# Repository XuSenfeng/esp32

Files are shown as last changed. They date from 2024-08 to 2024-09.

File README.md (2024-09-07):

# esp32
通过这一个项目可以实现一个带有氛围灯的esp32 Wifi 天气时钟, 这一个项目里面的教程包括PCB设计, 3D打印外壳的设计, 软件的设计

成品图片

[这一个是v1.0的的测试视频](https://www.bilibili.com/video/BV1RnYReXEdh/?spm_id_from=333.999.0.0), 目前这一个开发板的硬件还有一点bug(led的灯光不稳定), 目前猜测是电压问题或者信号干扰, 但是由于最近比较忙一直没有实际测试, 以后有时间会优化的

目前在测试Mqtt远程实现一个弹窗信息提示

其他的学习资料可以看一下这一个[嵌入式学习路线 (know-cnu.wiki)](https://embedded-study-guide.know-cnu.wiki/)

实际使用的是ESP-IDF v5.1.4



使用自己的分区表



lvgl使用QR库

```c
dependencies:
  espressif/esp_lcd_touch:
    component_hash: d4d8f2dc33205797169a97a02e0d89a8982f59fe0509129b54422052b8522f59
    source:
      storage_url: file:///E:/alearn/ESP-IDF-5_1_4/Espressif/registry
      type: service
    version: 1.1.1
  espressif/zlib:
    component_hash: 999ec50086ac1c82b8321d8f540dc9fd10f5622948b935558aa16b4b66e95d9d
    source:
      type: service
    version: 1.3.0
  espressif__esp_lcd_touch_ft5x06:
    component_hash: null
    source:
      path: E:\JHY\esp32\ESP-IDF\2024-8-3-jiao-ESP32\components\espressif__esp_lcd_touch_ft5x06
      type: local
    version: 1.0.6
  idf:
    component_hash: null
    source:
      type: idf
    version: 5.1.4
  lvgl/lvgl:
    component_hash: 948bff879a345149b83065535bbc4a026ce9f47498a22881e432a264b9098015
    source:
      storage_url: file:///E:/alearn/ESP-IDF-5_1_4/Espressif/registry
      type: service
    version: 8.3.11
manifest_hash: f8acd3c53fe97b7bd7f866e9e690cc329aa47d9190d9542797e4897a80c30134
target: esp32
version: 1.0.0
```

> 使用的组件和版本

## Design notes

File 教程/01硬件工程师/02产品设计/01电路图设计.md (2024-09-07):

---
layout: post
title: "电路图设计" 
date:   2024-8-5 15:39:08 +0800
tags: 教程
---

# 电路图设计

## 产品需求

1. 想要一个物联网适合练手的产品, 简单, 成本低, 可以练习的方向比较多
2. 想要一个屏幕, 用于和用户进行交互
3. 实际使用的时候可以保证有一种简单的交互方式
4. 装饰性
5. 尽量把大部分引脚印出来, 方便之后的拓展

### 器件选型

使用esp32的芯片设计一个天气时钟, 同时有多个可以操控的外设, 同时不会导致设计的难度过大

低成本外设: LED灯珠, 最好可以有多种颜色



> 选择这一个LED氛围灯常使用的LED灯珠

屏幕: 使用淘宝常见的屏幕模块



> 选择这一个成本比较低但是可以实现彩色显示的屏幕

核心芯片: 需要有WIFI, 由于有显示之类的需求, 内存比较大, 设计时候外部电路尽量比较简单, 之后会使用SPI, I2C之类的外设, 可硬件实现最好, 芯片方便购买, 综合以上的内容, 主芯片选择ESP32

这里是B站up主整理的[ESP32选型](https://www.bilibili.com/read/cv15539489/)手册, 也可以使用[官方的整理工具](https://products.espressif.com/#/product-selector?language=zh&names=)



最后选择使用这一个模块, 可以满足所有的需求

我还想实现一下获取当前的室内温湿度的功能, 这里为了简化设计直接抄了[嘉立创的设计](https://lceda001.feishu.cn/wiki/L5Qhw037viVW5MkyFXPcRLhznbe)(之后会讲)



在下载电路这里使用的是嵌入式里面比较常用的ch340系列的芯片, 为了焊接方便使用Micro-USB接口, 焊接技术比较高的也可以尝试使用USB

电源由于esp32需要3.3V电压, USB供电提供的是5V电压, 所以使用一个常用的稳压芯片AMS1117-3.3

按键的选择由于开发板的大小, 所以使用的是两个引脚的小按键

## 电路设计

电路参考:

[‌‌‌‍‌‍‬‍‌‍‍‌‍第02章.【立创·实战派ESP32-C3】开源硬件 - 飞书云文档 (feishu.cn)](https://lceda001.feishu.cn/wiki/BbarwCC29iqFESkr19fcaqrenAb)

[RYMCU - 嵌入式知识学习交流平台](https://rymcu.com/products?page=1)

资料

[模组概览｜乐鑫科技 (espressif.com)](https://www.espressif.com/zh-hans/products/modules): 记录乐鑫的各种模组

[esp32-wroom-32_datasheet_cn.pdf (espressif.com)](https://www.espressif.com/sites/default/files/documentation/esp32-wroom-32_datasheet_cn.pdf): 实际使用的模组

从这一个文件里面可以获取主体电路的设计方案



> 主要有:
>
> 1. 下载选择电路--IO0
> 2. 串口电路: TXD0, RXD0
> 3. 调试电路: JTAG没有使用
> 4. 电压电路
> 5. 复位电路

### 电压电路

从[数据手册](https://atta.szlcsc.com/upload/public/pdf/source/20210915/EA806799CEEC3F52E0A4FA8303A508AC.pdf)里面可以获取这一个芯片的基本信息



AMS1117有固定和可调两个版本可用，输出电压可以是：1.2V，1.5V，1.8V，2.5V，2.85V， 3.0V，3.3V，和5.0V。片内过热切断电路提供了过载和过热保护，以防环境温度造成过高的结温。

> 
>
> 

从[这一个手册](https://item.szlcsc.com/323882.html)可以获取一个参考电路, 我们使用的是固定电压的版本



> 对这一个电路分析, 里面有两个稳压电容用于使这一个电路的电压稳定

之后从[这一篇文章](https://blog.csdn.net/qyx3868/article/details/124667109)里面获取到了一个和参考开发板比较像的电路图, 增加了另外两个小电阻, 最后加入一个保护电路的保险丝, 即可完成这一个输入电路的设计方案, 加了一个led用于显示这一个电路是不是已经连接电压



### 下载电路

#### 一键下载电路

[ESP-Prog 下载与调试板介绍 - - — ESP-IoT-Solution latest 文档 (espressif.com)](https://docs.espressif.com/projects/esp-iot-solution/zh_CN/latest/hw-reference/ESP-Prog_guide.html)

从这一个文件里面可以获取使用ESP32-IDF的时候使用的一键下载电路



这里不同引脚起到的作用可以在我的esp32软件笔记里面找到

直接抄了一下







手册里面说默认EN引脚会使用一个电阻上拉, 但是实际测试的时候这一个引脚的电压达不到需要的电压, 所以使一个电阻进行一个弱上拉, 以及田添加了一个弱上拉

#### USB转串口







这一个芯片是经常使用的USB转串口的芯片, 由于esp32的一键下载电路里面有使用到这两个引脚, 所以在实际选择的时候可以最好选择有这两个引脚的芯片, 我最后选的芯片是CH340K这一个芯片





基本所有的引脚都可以使用到

### LED灯

由于使用的是WS28112B这一个LED灯, 所以参考他的手册设计即可

[WS2812B-2020_worldsemi_WS2812B-2020中文资料_PDF手册_价格-立创商城 (szlcsc.com)](https://item.szlcsc.com/1051115.html)



> 在实际使用的时候, 出现LED灯闪烁的情况, 猜测1. 电压不够 2. 有干扰 
>
> 由于比较忙一直没有测



### 排针

我这里是把所有的引脚都留出来了, 具体的排布是根据芯片的引脚的顺序排的

### 注意事项

1. 有的GPIO不可以进行输出
2. 串口接线需要交叉布线
3. 天线下面不能铺铜
4. 改完以后需要重新铺铜以及添加泪滴
5. 可以加一个下载使用的位置

#### IO分布

esp32的I2C和SPI可以连接任意的引脚, 所以可以随意地设计, 实际设计的时候需要注意, 有的GPIO是不可以输出的, 不能输出的按键上拉好像是不太行的, 不建议做按键输入

[esp32_datasheet_cn.pdf (espressif.com)](https://www.espressif.com/sites/default/files/documentation/esp32_datasheet_cn.pdf)这一个手册里面记录有引脚的功能

还有就是注意一下实际的引脚的作用和分布的位置, 比如LED和它的控制引脚最好离得近一点

## PCB设计

PCB直接电路图转过去, 由于嘉立创的免费打样好像限制了板子的长宽, 所以无选的比较长的一边是10cm, 另一边由于需要固定外壳, 所以我在外面留了一部分

在实际布局的时候按照[教程](https://www.bilibili.com/list/watchlater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)就可以自己实现, 所以这里说几个我遇到的注意点

1. 如果使用的是Type-c使用手工焊接会比较困难

2. 尽量让芯片离USB接口等比较高的元器件远一点

3. 屏幕我的排针是按照我的屏幕设计的

4. ESP32的天线下边最好不要有铺铜

5. 铺铜的时候注意把比较尖的位置设置一个禁止区域

6. 底层丝印在不翻转板子的情况下是镜像的

7. 过大电流的位置如果要换面多打几个孔

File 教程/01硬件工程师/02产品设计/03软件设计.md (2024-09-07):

---
layout: post
title: "软件设计" 
date:   2024-8-5 15:39:08 +0800
tags: 教程
---

# 软件设计01

时间原因, 暂时是按照各个文件的内容进行讲解, 之后有空会进行项目构建讲解



这一个程序直接使用了嘉立创开发板的屏幕驱动程序, 之后去除里面的触摸屏等, 改编而来, 之后主要讲解的是app以及bsp下面的文件, data文件大部分是lvgl网站工具生成的

## 程序分析

### 主程序

```c
#include "app_main.h"
#include "freertos/FreeRTOS.h"
#include "freertos/task.h"
#include "key.h"
void app_main(){
    key_init();
    led_init();
    xTaskCreate(spi_lcd_main, "spi_lcd_main", 4096, NULL, 5, NULL);
    xTaskCreate(wifi_main, "wifi_main", 4096, NULL, 5, NULL);
    xTaskCreate(mqtt_main, "mqtt_main", 1536, NULL, 5, NULL);
}
```

> 首先初始化一下两个使用的外设, 之后创建三个主要的线程, 分布用于图形界面显示, 网络连接的处理, 以及远程连接的处理

### 屏幕显示界面

```c
/*

                天气界面3
                   ||
   二维码1  ==  时钟界面0  ==  按键界面2
                   ||
               led控制界面4
*/
```

主要是移植了lvgl的官方示例, 把里面的触摸屏相关的示例删了

spi_lcd_main=>lvgl_screen_init初始化=>lv_demo_main显示一下主界面=>led_creen_main创建一个控制屏幕显示的任务=>不停地刷新界面

#### spi_lcd_touch.c显示初始化/控制

这一个文件里面一部分的函数是esp32官方例程里面的函数, 保持原样即可使用, 大部分是example开头的, 主要实现的功能是根据按键, Wifi等的事件显示不同的界面

最开始是头文件以及初始化一些使用到的全局变量以及宏定义

+ example_notify_lvgl_flush_ready

初始化一变量, 在初始化的时候使用这一个函数, 这一个回调函数在颜色传输结束的时候调用

+ example_lvgl_flush_cb

实际用于显示的函数, 可以在这里放上实际的显示函数\

+ example_lvgl_port_update_callback

初始化参数变化的时候会调用这一个函数, 这一个函数实际的作用是lvgl显示的旋转

+ example_increase_lvgl_tick

lvgl的时钟处理函数, 需要一段时间调用一次

+ button_read

注册的按键回调函数, 这一个文件里面把中间的按键注册为lvgl的外设, 按下这一个按键相当于点击屏幕的中间

+ lvgl_screen_init

初始化屏幕的驱动以及lvgl的初始化, 会在这一个函数里面初始化一下SPI以及把屏幕相关的设置进行初始化

之后对lvgl进行初始化, 在初始化lvgl的时候把中间的按键初始化为lvgl的一个设备

+ led_screen_change

实际处理屏幕的转换的函数

+ led_creen_main

控制屏幕变化的主函数, 这一个函数之后会被注册为一个任务

主要的功能是调用按键的处理函数, 之后根据按键的返回值处理不同的界面任务, 根据返回值处理如果是界面变化调用led_screen_change, 不是的话判断当前界面是不是时间显示界面, 是的话使用lv_update_time更新时间

这一个函数在处理按键的时候是一个限时的阻塞读取

在处理这些以后判断一下当前的屏幕是不是该息屏, 是的话关闭背光

+ spi_lcd_main

主函数, lvgl_screen_init初始化=>lv_demo_main显示一下主界面=>led_creen_main创建一个控制屏幕显示的任务=>不停地刷新界面

### 网络相关

#### lv_demo.c各个页面的显示

所有的界面的显示都是在这一个文件里面实现的

```c
LV_IMG_DECLARE(background)
LV_FONT_DECLARE(ledfont)
LV_FONT_DECLARE(wether_font)
LV_FONT_DECLARE(icon)
```

> 开始的时候使用这几行进行lvgl数据的导入, 分别是背景图片, 三种字符

之后是定义一下需要使用的全局变量, 包括时间结构体以及声明使用的外部变量, 用于获取led信息以及主要使用的用于同步的事件组EventGroupHandle_t

```c
//当前的时间
time_t now;
struct tm timeinfo;
//记录led的现在的情况
//这一个数据会在led的线程里面控制了的的随机显示
extern uint8_t led_state;
extern EventGroupHandle_t my_event_group;
```

+ led_button_cb

是在操控led随机显示页面的时候中间的按钮的回调函数, 由于初始化的时候把中间的按键初始化为lvgl的按键外设, 设置按压的位置是在屏幕的中央, 所以在这一个界面可以通过实体按键控制

+ lv_update_time

时间更新函数, 这一个函数里面会获取当前的时间, 把时间显示在屏幕

+ lv_demo_main

启动界面的demo, 显示一下基础信息以及获取时间的进度

+ lv_demo_switch

切换led随机显示的界面

+ lv_demo_time

显示时间的界面, 这一个函数会把里面的table返回, 作为之后刷新时间的时候使用

+ lv_demo_wifi

这一个函数是在Wifi连接以后显示的二维码的界面

+ lv_demo_led

控制led灯颜色的界面

+ lv_demo_get_wether

等待获取天气的页面

+ lv_qweather_icon_show

显示实际天气的图标, 依据获取的天气进行不同的显示, 在lv_demo_wether函数里面调用

+ lv_demo_wether

显示天气的界面

+ lv_demo_msg_win

弹窗初始化, 如果已经初始化, 会在这里面显示

+ deal_page4 处理led控制页面

传入的参数是按下的按键, 根据不同的按键, 更新一下当前的led的选择的位置

当这一个选择的位置是在最下面的时候, 第一次选择进入颜色选择, 第二次把这一个颜色写入

实际的当前位置使用以下三个变量进行记录

```c
int led_choice = 0; // 选择的灯
char choice_now_pos = 0; // 选择的灯的位置, 低四位为行, 高四位为列
unsigned char choic_color[3] = {255, 0, 0};
```

#### wifi.c连接wifi以及服务器

主要实现wifi里面, 初始化一个服务器, 可以用于和手机进行通信, 以及时间的获取

wifi_sta_init初始化wifi的各种数据以及开启wifi=>wifi_cb回调函数, 处理wifi的各种状态

这里面有一个wifi_main线程, 在这一个线程里面实际实现的是一个网页服务器

+ get_time

从服务器获取时间, 之后把这一个时间更新一下, 这一个函数是在界面管理的函数里面调用的

+ wifi_cb

用于wifi链接的回调函数, 在启动以后会进行wifi的链接, 链接成功设置WIFI_CONNECTED_BIT标志位

+ 两个页面

这两个页面是html格式的页面, 实际的作用分别是用于控制led, 以及成功提交以后的提示界面

+ get_handler

使用get方法访问第一个页面的时候返回第一个页面

+ post_handler

处理使用post方式访问第二个页面的函数, 会在这里解析第一个页面传过来的的数据, led_message_deal这一个函数会把字符串里面的led以及颜色信息填入led信息记录数组里面

+ _http_event_handler

http的事件理函数, 这一个函数是服务器使用的, 获取不同的http请求的时候, 会触发不同的事件

这一个函数是示例里面的函数

+ gzDecompress

GZIP的解压函数, 用于处理获取到的天气信息

+ get_now_weather

获取当前的天气, 使用API获取, 这里的API使用的是嘉立创教程里面获取的API, 获取信息以后使用gzip进行解压, 然后使用cJSON进行解析, 获取的信息记录在全局变量里面

+ wifi_main服务器主函数

在这一个函数里面注册两个页面, 分别处理不同的http请求, 之后使用网页进行操控的时候会触发_http_event_handler函数

+ wifi_sta_init初始化wifi

初始化一下wifi, 设置一下回调函数

#### mqtt.c远程连接

这一个主要是实现远程的信息通信, 使用mqtt_main为一个线程处理mqtt的信息

+ deal_message

处理mqtt获取的信息, 使用cJSON进行解析, 把获取的信息进行显示, 同时使用一个led显示红色进行提醒

+ mqtt_event_fun

MQTT事件处理函数, 在连接的时候, 订阅一下Jiaoesp这一个主题, 在获取信息的时候调用deal_message处理信息

### 驱动

#### jiao_i2c.c i2c的驱动文件

由于我的开发板没有焊接温湿度传感器, 所以暂时没有使用, 这一个文件里面实际是一个初始化i2c

#### key.c 按键处理

在这一个文件实现按键的处理, 主要是各个页面的切换

+ page4_init

在进入page4之前把用于记录信息的全局变量清零一下

+ key_deal 处理实际的按键

依据当前的按键的位置, 进行不同的处理, 返回值是一个char数组, [0]: 是否需要处, [1]: 当前的页面, 这一个函数的调用是在lvgl的界面处理函数例程面, 使用xQueueReceive阻塞, 如果返回界面需要变化的时候清空一下对弹窗的记录信息

如果当前是息屏, 唤醒屏幕

+ key_isr_handler

中断处理函数, 在这里面把获取的当前的按使用Queue发送处理, 发送的数据会在key_deal函数里面进行处理

+ key_init

初始化一下按键的gpio以及注册一下按键的中断处理函数

#### led_control.c

ws2812b的驱动函数

开始的时候是一些方便操控的宏定义, 之后是一些用于实现通信协议的函数比如delay_ns, ws2812b_rst, ws2812b_writebyte_byt, ws2812b_write_rgb_byte

在这一个文件里面, 我使用led_color这一个数组记录所有的led的颜色, 有几个用于设置里面的颜色的函数, w2812b_close_color_set关灯, getrandom_color获取一个随机的颜色, init_random_led_color把所有灯设置为随机颜色

+ led_flash

把led_color里面的颜色进行实际的显示

+ led_update_color

page4里面的处理函数, 用于把当前的设置的led进行实际的设置以及显示

+ led_message_deal

处理http获取的post信息, 获取要设置的led和颜色, 最后进行刷新

+ led_close

关灯

+ ws2812_task

led的任务, 这一个任务的功能是进行led的实时显示, 用于实现随机led显示等

+ start_task

启动任务

+ gpio_pad_select_gpio

初始化一个led的引脚

+ led_init

初始化函数, 初始化gpio以及启动一下这一个任务

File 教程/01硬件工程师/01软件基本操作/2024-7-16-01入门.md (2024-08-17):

---
layout: post
title: "入门" 
date:   2024-7-14 15:39:08 +0800
tags: Linux 网络
---

# 软件下载

使用立创EDA

[软件下载 - 嘉立创EDA (lceda.cn)](https://lceda.cn/page/download?src=index)



下载激活即可

## PCB定义

Printed Circuit Board 印刷电路板

作为元器件的制成, 实现电子元器件的连接

### 层叠结构

在铜皮上面做减法, 去除不需要的部分, 铜皮容易被折断, 所以把铜皮放在一个基板上面,直接裸露的时候, 这一个铜皮容易被腐蚀,  覆盖一层绝缘的绿油(阻焊), 同时可以防止触电, 还可以防止焊锡乱走

在板子上面做一些标志, 标志的名字叫做丝印

元器件比较多的时候, 连接比较复杂, 这时候可以有多层的铜皮, 不同的层之间可以进行打孔进行连接

内部的线和外部的器件进行连接的时候, 需要根据不同的封装设计不同的接触面积, 体现在PCB就是裸露的焊盘, 使用阻焊开窗的方式实现





>   它可以在PCB工厂制造。一般情况下，四层板芯两侧压一铜箔，三层板芯一侧压一铜箔。就工艺流程而言，有必要进行冲压。
>
>   两种工艺成本的差异在于，四层板材多了一层铜箔和粘合层，成本差异不大。板材厂报价时，一般以3-4层的报价为一个等级，报价以偶数定义（当然不止多层）。例如，如果你设计了五层板，对方会按照六层板的价格报价，即你设计了三层板的价格，价格与你设计的四层板的价格相同。
>
>   在PCB工艺中，四层板比三层板更容易控制。主要在对称性方面，四层板的翘曲度可控制在0.7%以下（ipc600标准）。然而，当三层板的尺寸较大时，翘曲将超过该标准，这将影响SMT贴片和整个产品的可靠性。因此，普通设计师不设计奇数层板，即使奇数层实现了功能，也将设计为伪偶数层，即5层设计为6层，7层设计为8层。
>

### 通孔, 盲孔, 埋孔

通孔: 从顶层到底层, 这一个PCB板被打通了, 内部镀铜

盲孔: 没有打通, 连接其中几层, 但是外部可以看到, 所以起点是第一层

埋孔: 进行内层的切换, 也是没有打通的

## 元器件符号和封装

元件在PCB上面的形式



> 黄色的是丝印层, 灰色的是焊盘的范围, 红色的是实际的焊盘, 每一个引脚对应一个焊盘

## 生产

+ 开料, 圆角, 刨边

开料把原始的覆铜板割为可以制作板子的过程, 铺铜板是双层板, 其余的多层板是使用这一个板子粘合而来的

+ 钻孔

这个时候孔里面是没有铜的, 根据实际有孔的层进行打孔

+ 沉铜

PCB在沉铜缸里面通过氧化还原对孔进行金属化

+ 压膜

铜箔板的两个面各贴一张蓝色的感光膜。

感光膜作用是在铜箔板上完成线路的印制，它只在铜箔板上保留一段时间，在后续的“图电”步骤完成后，铜箔板上的膜就消失了，它的使命就完成了。

+ 曝光

线路菲林有线路的地方是黑色的，没有线路的地方是透明的，在曝光灯管的作用下，透明的地方就会充分曝光，也就是**没有线路的地方会充分曝光。**

经过曝光后，干膜上就有清晰的线路了

>  菲林就跟模具一样，而PCB就是材料。做PCB的时候，需要把没用的铜箔[蚀刻](https://zhidao.baidu.com/search?word=蚀刻&fr=iknow_pc_qb_highlight)掉。菲林就是在这里起了作用，首先，把菲林晒到网板上。

+ 显影

曝光其实就是为显影做准备。显影设备中的显影液会把没有曝光过的部分去掉，也就是说，它会把有线路的地方去掉，露出黄铜。

> 需要留下来的铜是在空气中的

+ 电铜

曝光其实就是为显影做准备。显影设备中的显影液会把没有曝光过的部分去掉，也就是说，它会把有线路的地方去掉，露出黄铜。

+ 电锡

电锡以后，有线路的地方，会再上一层锡，这里的锡，并不是我们最终拿到手电路板上的锡，这里的锡，是一种液态锡，它的作用是在下一个环节“退膜”的时候保护线路，它将会在图电工序的最后一个环节消失，完成它的使命。

+ 退膜

把蓝色的膜去掉, 只对曝光过的干膜起反应，经过两次退膜水洗，退膜就彻底完成了。

+ 蚀刻

干膜已经不见了，露出了铜，这些铜，都不是我们需要的，我们需要的铜，此时正在锡的下面。接下来板子进入蚀刻环节，目的就是把裸露的铜全部腐蚀掉。

经过蚀刻以后，刚才去掉干膜后露出的铜，就被腐蚀掉了。现在电路板上就只剩下真正需要的线路部分了。

锡没有和蚀刻药水发生反应，刚才的裸露铜部分，现在已经露出了基材。

+ 退锡

锡没有和蚀刻药水发生反应，刚才的裸露铜部分，现在已经露出了基材。

+ 光学AOI线路扫描

自动光学检测, 把待检测的电路板放到AOI仪器检测面板上，AOI仪器开始自动扫描电路板，并与MI文件中的相应文件进行对比，一旦有区别，就会停下来，把图像放大显示到显示器上。

如果是缺陷的话，看看是否能够补救，能补救的话就补救一下，不能补救的，就是生产缺陷了，然后标记一下出错地方。

AOI检测，只是针对电路板的外观进行检测，可以很好的检测出来开路、短路、断路的地方。

+ 阻焊

阻焊的目的，就是给电路板表面涂一层油，保护铜。最常见的是绿油，此外，还有蓝、黑、白、红、黄、紫等颜色。目前，嘉立创针对不同颜色的阻焊工艺，全部免费。

+ 曝光

在不需要绿油覆盖的地方，也有了绿油，比如焊盘等需要开窗的地方。为了去除这些地方的阻焊油，就需要经过曝光和显影。

曝光需要用到阻焊菲林，在菲林上，需要开窗的地方是黑色的，其它地方是透明的。经过曝光以后，透明的地方就进行了充分的曝光，黑色的地方没有被曝光，就是需要开窗的地方，没有被曝光。

+ #### 显影

也是一个化学反应的过程，显影液只对未曝光的地方起反应，所以，需要开窗的地方，就裸露出了焊盘

+ 字符

丝印, 标志打印上面

+ 表面处理

字符工序完成后，就该喷锡或沉金了。我们在嘉立创下单PCB的时候，会在焊盘喷镀那一栏选择“喷锡”还是“沉金”。喷锡后的焊盘，被上了一层锡，是银色的；沉金后的焊盘，被镀了一层金，是金色的。

+ 测试

板子进行了AOI光学检测，主要是从外观上，针对开路、短路、断路等情况对电路板的表面进行了检测，无法知道过孔的问题，比如孔内是否有铜、铜的质量如何、是否可以正常导通。

> **飞针测试:** 通过检测电容值来判断。在开始测试前，工作人员先把电路板固定到机器上，然后导入电路板的网络文件，机器电脑会计算好每个网络的电容标准值，当测试开始以后，如果容差超过了一定范围，就认为不合格。
>
> 在开始测试前，工作人员先把电路板固定到机器上，然后导入电路板的网络文件，机器电脑会计算好每个网络的电容标准值，当测试开始以后，如果容差超过了一定范围，就认为不合格。
>
> **复合模具测试: **飞针测试完成一张电路板，需要的时间并不短。为了很好的解决时间的问题，复合模具测试，就诞生了。
>
> 复合模具测试虽然快，但是需要制作一个复合模具，复合模具是由一层一层的板子组成的，包括插针、打线、排线等。制作模具需要一定的成本，还有时间，所以，复合模具测试，更适合大批量的电路板测试，如果是样板，还是飞针测试比较适合。
>
> 在复合模具中，会有很多的探针，一次性压到电路板上，完成测试，很明显，它比飞针测试中的4个探针逐点移动要快很多。

+ 锣边成型和V-CUT

把大板分成小板了，每一个小板，就是每一个客户设计的电路板，最终会把这些小板对应的发给不同的客户。

V割和锣边的区别就是，锣边会直接把两张电路板分开，而V割后的电路板，两张电路板之间没有被完全割开，还留有一部分，只需要稍微用力，就可以掰开。

+ 质量检测

QC，即质量检测。在这个环节，主要通过人工进行检测，主要检测板子外观和板子数量是否达标。板子外观方面，主要看是否有明显的缺陷，比如划伤、字符模糊等，还需要检测需要V割的板子是否有V割过。

## PCBA

印刷电路板+组装的缩写, 空的PCB经过SMT贴片加载以及DIP插件安装, 整个过程叫做PCBA

## 焊接

浸焊: 浸焊是大量应用在插件工艺及[SMT红胶](https://baike.baidu.com/item/SMT红胶/2694579?fromModule=lemma_inlink)面，利用手工或机器，把大量的锡煮熔，把焊接面浸入，使焊点上锡的一种多点焊接方法。

> 用于直插件的焊接

回流焊: 使用钢网, 锡膏, 用于贴片

波峰焊: 也是用于插件

## 多层PCB的经典方案

### 四层板

多了两层可以操控的空间

最常使用的方案是顶层和底层放置元件, 另外的两层分别为GND和PWR

一般使用的时候会把GND层设置在主要的元件所在的层附近

如果元器件大多数是插件, 也可以考虑把GND为顶层, PWR为底层, 中间的是走线层

### 六层板

+ TOP-GND-S1-S2-PWR-BOTTOM

电压阻抗比较小的时候可以使用这一个, 地平面比较少电磁的吸收能力比较少

并且PWR和GND耦合比较差

+ TOP-S1-GND-PWR-S2-BOTTOM

有比较好的电磁吸收能力, TOP和BOTTOM层的参考不是特别好

+ TOP-GND-S1-PWR-GND-BOTTOM

**最佳的方案**: 设计了多层参考地平面, 使得叠层有非常好的参考地平面

### 八层板

+ TOP-GND1-S1-PWR1-GND2-S2-GND3-BOTTOM

最佳的方案, 有多个参考使用的地平面, 有比较好地磁吸收能力

> 关键的信号层要和地相邻, 信号层之间尽量不要相连
>
> 相邻的层之间的布线尽量不要平行

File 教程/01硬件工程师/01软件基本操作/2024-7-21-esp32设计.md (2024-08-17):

---
layout: post
title: "esp32设计" 
date:   2024-7-14 15:39:08 +0800
tags: Linux 网络
---

# esp32设计

[esp32-wroom-32_datasheet_cn.pdf (espressif.com)](https://www.espressif.com/sites/default/files/documentation/esp32-wroom-32_datasheet_cn.pdf)

[esp32_datasheet_cn.pdf (espressif.com)](https://www.espressif.com/sites/default/files/documentation/esp32_datasheet_cn.pdf)

这里使用的是esp32的一个模组

[模组概览｜乐鑫科技 (espressif.com)](https://www.espressif.com/zh-hans/products/modules)

esp32的技术规格书, 里面有GPIO的定义

[esp32_datasheet_cn.pdf (espressif.com)](https://www.espressif.com/sites/default/files/documentation/esp32_datasheet_cn.pdf)

## 出现的问题

1. 有的GPIO不可以进行输出
2. 串口接线需要交叉布线
3. 天线下面不能铺铜
4. 改完以后需要重新铺铜以及添加泪滴
5. 可以加一个下载使用的位置



## type-c转串口







## LED

[主要特点 (szlcsc.com)](https://atta.szlcsc.com/upload/public/pdf/source/20211224/E1D51490BF3990BC3747CA833459C67A.pdf)



## IO分布

esp32的I2C和SPI可以连接任意的引脚, 所以可以随意地设计, 实际设计的时候需要注意, 有的GPIO是不可以输出的

[esp32_datasheet_cn.pdf (espressif.com)](https://www.espressif.com/sites/default/files/documentation/esp32_datasheet_cn.pdf)这一个手册里面记录有引脚的功能

0. 无
1. 无
2. **KEY**
3. 无
4. 无
5. **LCD**
6. 无
7. 无
8. 无
9. 无
10. 无
11. 无
12. **KEY**
13. **LCD**
14. **LCD**
15. 无 ==KEY
16. **LCD**
17. **LCD**
18. LCD
19. **KEY**
20. 无
21. **KEY**
22. I2C
23. I2C
24. 无
25. **KEY**==>LED
26. **KEY**==>LED
27. **KEY** 
28. 无
29. 无
30. 无
31. 无
32. LED
33. 无
34. 无//LED==>key//
35. 无//LED==>key
36. 无
37. 无

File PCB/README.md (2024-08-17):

# README

打开方式





选择这一个目录下的项目文件

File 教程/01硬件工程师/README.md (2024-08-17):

# README

这一个内容学习需要有电路的支持储备, 以及了解单片机的工作原理

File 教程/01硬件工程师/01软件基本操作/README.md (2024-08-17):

# README

这一个文件夹的内容是我学习[此课程](https://www.bilibili.com/list/watchlater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)时候的笔记, 时间还没有进行优化, 之后会针对学习进行优化

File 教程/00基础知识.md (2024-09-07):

---
layout: post
title: "基础知识" 
date:   2024-8-17 15:39:08 +0800
tags: 教程
---

# 基础知识

**注: **最新版[嵌入式学习路线 (know-cnu.wiki)](https://embedded-study-guide.know-cnu.wiki/)

这一篇文档记录我当前学习的经历里面比较值得推荐的课程以及书籍, 在实际学习的时候, 有不会的直接百度, 推荐使用必应搜索, 下面记录的知识里面大部分我都记有[笔记](https://github.com/XuSenfeng/note), 可以参考一下, 但是我的笔记大部分是为了我自己查阅, 所以有可能不是很清晰

> 我的主要学习方向是嵌入式系统, 以及物联网
>
> 这一个笔记是我的笔记库, 是最新的, 论坛上的可能不会及时更新

## 必备知识

这一个部分是入门嵌入式必备的基础知识, 不管之后发展到哪一个方向到需要用到

### C语言基础

嵌入式由于接触的内容是比较底层的内容, 所以大部分的开发使用的是C语言, C语言可以更方便的操控内存以及可以使用比较小的内存实现功能, 保证开发效率的同时兼顾难度

我的C语言是在学习了[C++课程](https://www.bilibili.com/list/watchlater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)以后通过[这一个课程](https://www.bilibili.com/list/watchlater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)学习入门的, 之后通过阅读《C和指针》以及《C陷阱与缺陷》

学习完C语言基础教程之后就可以开始学习嵌入式了, 数据类型以及基础算法在我的理解中是不需要特地学, 代码看了多了常用的基本都会了, 不常用的到时候现找就行, 重点在于基础语法以及编程思路的建立(不适用于比赛)

### 电路知识

我这一个部分的内容在学习的时候大部分是根据[这一个视频](https://www.bilibili.com/list/watchlater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)进行的, 同时在学习的时候也需要有扎实的电路基础, 这里推荐两个视频[电路](https://www.bilibili.com/list/watchlater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)和[模电](https://www.bilibili.com/list/watchlater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), 在实际学习的时候不需要全部融会贯通, 只需要掌握基础的电路原理以及元件性质已经可以满足现阶段的大部分的问题

之后根据实际面对的问题针对性学习即可, 避免在没有对实际应用充分了解之前把时间浪费在不相干的学校课程安排(有保研需求除外)

> 注: 电路里面的电容电感的基本性质, 电路里面的基础分析方法, 以及模电的第一章

## 嵌入式入门

可以看一下《嵌入式C语音的自我修养》了解一下编译链接之类的编程基础知识

### 51单片机

经典单片机, 入门级单片机, 可以用于了解单片机的基础知识

我学习的课程是[这一个](https://www.bilibili.com/list/watchlater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), 购买一个二手的开发板就够学习用了, 可以看一下郭天祥的书(非必要)

看完以后可以试着自己搭建一个最小系统板之类的练练手

了解寄存器的知识, 单片机的简单操作, 基础外设的使用以及通信协议, 中断的使用等

### stm32

经典的ARM架构开发板, 可以了解现在比较通用的各种外设以及编程思想

我学习的课程是[这一个](https://www.bilibili.com/list/watchlater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), 从标准库开始打牢基础, 之后学习封装等级比较高的HAL库的时候可以自己有能力找出来出现的问题, 听说[这一个视频](https://www.bilibili.com/list/watchlater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)的质量也很高但是我没有看过

> 不要迷信各种示例代码(包括官方代码), 有独立的查手册的能力以及翻阅源码的能力, 以官方手册为准, 出现问题可以去官方社区提问(我之前遇到过官方代码和手册有矛盾的情况, 工作人员说以手册为准)

学习完基础以后可以了解一下HAL库的使用, HAL库是更高一层的封装, 但是不了解底层的话出现问题难以排查, 以及会出现效率低的问题, 但是可以更高效的生成代码, 我学习的是[这一个课程](https://www.bilibili.com/list/watchlater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), 但是据我所知的课程大多脱离CubeMX, 导致学习起来这一个工具使用会不顺畅, 可以买一本《STM32Cube高效开发教程》当做字典进行查阅, 这时候的水平已经可以备战一下蓝桥杯嵌入式赛道了

## 提升

### 嵌入式软件

学习嵌入式常用的框架, 可以减少大量的开发时间, 在实际学习的时候首先需要了解这一个框架的基础使用方法, 之后有能力的话可以深入了解一下源码(我的笔记里面有相关的内容可以参考一下)

#### FreeRTOS

嵌入式使用最多的一个操作系统, 网上的课程暂时没有看到水准比较高的, 可以参考一下野火的书, 他的视频剪辑比较乱, 照着书看会比较容易理解, 之后可以直接看源码, 网上有很多的源码解读

#### lwip

以及简单的嵌入式网络框架, 可以用于实现sockt相关的接口, 用于实现网络编程

[【正点原子】手把手教你学lwIP网络编程协议-虚神疯-稍后再看-哔哩哔哩视频 (bilibili.com)](https://www.bilibili.com/list/watchlater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)

#### lvgl

一个图形化界面框架, 可以在使用很少的资源的情况下运行, 我学习的时候参考的课程是[这一个课程](https://www.bilibili.com/list/watchlater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)

#### RT-Thread

一个国内的嵌入式系统, 可以很方便的移植其他的框架(图形化界面), 虽然使用的人数不如FreeRTOS但是发展的速度很快, 主要参照官方给的教程以及手册, 很详细, 我的笔记里面把代码加了一下注释, 之前发在CSDN上了一部分

[2021最新RT-Thread实时操作系统教程，入门到精通全套完整版-虚神疯-稍后再看-哔哩哔哩视频 (bilibili.com)](https://www.bilibili.com/list/watchlater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)

#### 芯片内核

推荐书本《cotexm3权威指南》

cotex m3是一个经典的芯片内核, 这一个内核里面的很多知识在RISC-V架构里面也有借鉴, 配合嵌入式系统食用效果更佳

#### MQTT框架

韦东山的课程, 在他的公众号可以在活动的时候一分钱购买, 了解一下这一个通信协议, 以及使用简单的wifi芯片进行实现, 他的课程也可以作为一个项目的实践

#### 各种的模块使用

可以看一下屏幕模块, 温湿度模块的使用, 之后就可以开始自己实现一些项目了

### 硬件方向

因为我主要的方向不是硬件所以这一个方面我不太清楚, 我学习的大致层次就是够我自己做一些小东西出来以及复刻大佬开源的物品(稚晖君的小电视等)

#### PCB绘制

[可以使用立创eda](https://www.bilibili.com/list/watchlater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), 这一个软件的使用比较简单, 但是之后最好还是学习一下AD之类的专业软件

#### 3D建模

我主要使用这个来进行外壳的绘制, 所以学习的比较少, 用的软件是[SOLIDWORKS](https://www.bilibili.com/list/watchlater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)

## 其他

### Linux基础操作

了解Linux操作系统的基础指令以及使用, 建议使用ubuntu进行入门, 可以使用这一个了解一下电脑基本的运行原理

推荐书籍: 鸟哥的Linux私房菜

如果想要进行嵌入式Linux开发, 可以看一下[正点原子](https://www.bilibili.com/list/watchlater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)的课程, 从这里可以学习到Linux系统比较底层的知识, , 但是这一个课程在某些地方讲的不是很详细, 内容又比较难, 所以需要有比较强的自学能力

### 系统、网络编程

了解一下Linux系统上面的基础编程, 可以看一下[黑马的课](https://www.bilibili.com/list/watchlater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), 这一个up还有一个网络编程的课, 实际学习的时候把这一个课当做框架, 实际的知识点不清晰的使用网络找资料补全

理解一下多任务编程以及网络编程的基本思想, 学习一下socket编程的编程思想, 同时了解一下网络编程的基本协议, 在之后其他平台的开发里面有调试的能力

### python

可以用于写简单的上位机, 实现单片机和电脑的交互, 基础课程网上很多, 播放量比较高的都可以, 之后可以[看这一个up的系列教程](https://www.bilibili.com/list/watchlater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)补充一下底层的知识以及线程, socket相关的知识, 这个老师的pyQT也可以看一下, 可以用于实现电脑端的

### 前端

在实现物联网项目的时候, 有可能需要实现一个用户交互的界面, 用网页进行实现的时候需要知道最基础的前端知识, 会用即可, 基本会使用html和简单的CSS已经可以满足大部分的需求了

[黑马的课程](https://www.bilibili.com/list/watchlater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)

### 编译原理

了解一下编译的过程, 程序的预处理, 编译, 链接等过程, 以及了解一下不同机器架构的机器码的基础知识

之后可以使用Makefile以及cmake实现自己的编译脚本, 不必再依托于现有的环境

### 汇编

由于不同的机器内核里面的汇编代码是不同的, 所以这一个不需要去记住具体的指令集, 只需要知道汇编代码的基本逻辑, 可以在查手册的基础上实现简单的功能即可

[这个课程可以参考一下](https://www.bilibili.com/list/watchlater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), 但是由于依托的是课本, 所以有些比较落后, 我当时好像是用的Win7虚拟机学习的, 其他的一般系统开发的课程里面会有, 在使用的时候大部分起到的作用是为C语言建立环境以及操控C语言不能控制的寄存器

### 自制操作系统

**注 **: 这一个部分号称编程里面最难的一个方面, 量力而行

可以看一下《30天自制操作系统》这本书, 但是由于年代比较远, 有的操作需要在Win7的虚拟机里面实现, 我是使用VMware搭建的环境

之后进阶可以看李述铜老师的手写操作系统的课程, 价格比较高但是内容质量很高

通过这一个部分的学习可以充分理解操作系统的运行原理

### 其他的芯片

目前国内比较火的芯片是esp32, 推荐学习他的ESP-IDF开发方法, 这一个开发方式是目前主推的开发方式, 里面集成了比较常见的大部分框架, 比如说lvgl, lwip。在实际开发的时候可以使用系统里面自带的一部分驱动, 大大减少工作量, 但是多个框架的协调需要自己学习, 现在网上我没有看到比较全面的视频教程, 主要的参考资料是官方的文档和代码

> 可以看一下嘉立创的esp32板子附带的资料, 之后我的项目教程里面会有比较详细的介绍

还有比较火的芯片架构RISC-V, 这一个李述铜老师的课里面也有

学习了Cotex-m3内核以后就会发现大部分现在的内核以及芯片实现的功能都比较相似

## 具体方向的课程

嵌入式开发有很多不同的方向, 比如电机开发, 驱动开发, 因为我主要学习的是物联网开发, 所以不是很清楚

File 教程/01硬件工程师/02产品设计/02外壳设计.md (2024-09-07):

---
layout: post
title: "外壳设计" 
date:   2024-8-5 15:39:08 +0800
tags: 教程
---

# 外壳设计

我参考的[是这一个视频](https://www.bilibili.com/list/watchlater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), 我的设计目标是一个可以放在桌上的天气时钟

在实际设计的时候, 需要注意的点是

1. 设计的时候有一定的仰角方便观看
2. 有一个屏幕支持
3. 预留USB线的位置
4. 留出来按键的位置

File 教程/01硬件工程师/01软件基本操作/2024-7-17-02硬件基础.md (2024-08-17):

---
layout: post
title: "硬件基础" 
date:   2024-7-17 15:39:08 +0800
tags: Linux 网络
---

# 硬件基础

## 电阻

### 参数

TCR: 电阻温度系数, 电子温度改变1摄氏度的时候电阻的相对变化 ppm/℃, ppm(百万分之几)

>  α=(R2-R1)/R1(t2--t1)   R1--温度为t1时的电阻值，Ω; R2--温度为t2时的电阻值，Ω。单位是ppm的时候, 需要乘一个1,000,000

标准测量的温度是20℃, 正常的这一个参数是-200 ~ 500 ppm/℃, 应用在特殊温度的时候需要考虑

### 选型

#### 安装方式

+ 贴片

体积小, 容易焊接以及拆卸, 稳定性比较高, 可靠性高, 在数字电路里面的抗干扰能力比较强

可以使用SMP(贴片工艺进行大规模生产)

+ 插件

体积大, 可以承受大电流, 稳固不容易脱离, 便宜

> 选择的时候需要考虑功率, 成本, 焊接工艺

#### 阻值

电阻的阻值是离散的, 有一定的误差





电阻的标准是IEC(国际电工委员会)制定的, 标准的文件是IEC60063和EN60115-2

标称阻值有六大类  E6(%20), E12(%10) E24(%5) E48(%2) E96(%1) E192(%0.5)

> 一般使用的是E24, E96, E指的是指数间距
>
> 



+ 贴片电阻

三位数字代表的是5%的精度, 四位是1%的精度, 前面的几位是数值, 最后一位是10的x次方

如果里面有一个R, 阻值一般比较小, 精度为1%, R代表小数点, 前面的是有效值, 一般都是E96系列的电阻

> R100 => 0.1Ω

E-96规定两个数字加一个字母为丝印的时候, 实际的阻值通过查表进行获取



> 88A表示的是806, 前面的是行, 后面的是列

1. 实际使用的时候需要进行计算, 根据分压, 反馈, 取样获取
2. 通过手册获取
3. 通过经验, 上下拉以及部分的限流电阻

#### 精度



> 一般使用的是1%, 5%, 在ADC等需要精度比较高的地方使用其他电阻

#### 封装



主要使用的是0402, 0603, 功率比较高的时候使用1206

> 0201 => 长为0.02, 宽是0.01单位是英寸
>
> 换算1inch = 1000 mil
>
> 1mil = 0.0254mm
>
> 实际用的时候小数点直接进位 

#### 功率



功率和封装, 工艺, 品牌相关, 实际的信息查看数据手册

#### 温度



#### 额定电压

电阻的耐压值和电阻的材料以及封装大小有关



### 零欧姆

是一个特殊用途的电阻, 一般来说是50mΩ

1. 调试兼容
2. 作为跳线使用, 使用跳针的时候会有高频干扰
3. 实际是一个小电阻, 可以用于测量大电流(用的比较少)
4. 参数不确定的时候, 使用这一个进行调试
5. 高频的时候可以作为电感或者电容, 主要是解决EMC问题(电阻的实际模型)



6. 布线的时候, 实在是不能绕过去的时候使用这一个作为导线
7. 单点接地, 保护接地, 使得设备相互分离

> 当系统中存在多个接地点时，可能会形成地环路，这些环路会引起干扰和噪声，从而影响系统的正常运行。单点接地通过消除多个接地点，从根本上杜绝了地环路的产生。
>
> 多点接地容易导致各接地点之间出现电位差，这种电位差可能引起电流的非正常流动，影响设备的正常工作。单点接地确保所有设备共享一个接地点，从而避免了电位差的问题。
>
> 现代电子设备对电气环境的要求非常高，单点接地可以提供一个稳定的电气参考点，保障设备的正常工作。

8. 电路保护, 做一个低成本额熔丝, 比如使用0603作为USB电路的过流保护, 但是不推荐
9. 数字模拟电路一起使用的时候一般需要把两个地进行分离, 单点连接, 可以使用一个0Ω电阻连接, 地分为两个网络, 实际铺铜的时候比较简单, 有的时候也会使用电感以及熔丝
10. 配置电路, 起到开关的作用

## 电容

在两个导线之间, 会有一个寄生电容, 可以通过增加这一个寄生电容的方式减少原来电路里面的阻抗



在画PCB的时候, 有时候需要走线加粗, 根据电容的公式, 这时候寄生电容的相对面积加大, 容值加大(加大S)

在高速总线里面需要进行包地处理, 实际是通过加大电容减少阻抗(减小d)





其中为容抗，为感抗，为等效串联电阻。很容易看出，在频率比较低（比较小）的时候，容抗远大于感抗，电容主要成容性，在频率比较高的时候，电容主要呈感性。

而当，即谐振的时候，阻抗等于等效串联电阻，此时阻抗达到最小值，如果是用来滤波的话，此时效果最好。

### 类型



滤波电容: 电源和芯片之间加一个接地的电容, 使用电容充放电平缓电源的波动

旁路电容: 用于导通或者吸收某元件或者一组元件中交流成分的一种电容。通常交直流中的交流部分被去除，而允许直流部分通过加有旁路电容的元件。



耦合电容: 将交流信号的能量从一个电路传递到另一个电路的电容。可以将我们需要的交流信号从前级电路近似无衰减地耦合到后级电路，将我们不需要的直流信号进行去耦（隔断）



去耦电容: 去耦，在电子学中，表示不让能量通过一个电路传递到另一个电路。

自举电容

### 选型

#### 安装类型

陶瓷电容, 铝电容, 钽电容一般使用贴片的方式

安规电容一般使用的是插件的形式

####  电容值

1. 计算获取, 晶体振荡, LC滤波电容
2. 手册取值: 设计电路的时候
3. 经验: 滤波, 储能

> 供电电源上面一般会有一个0.1微法的电容, 几个芯片的供电一般使用一个10微法的电容

#### 电容的类型

一般小于10uF的使用陶瓷电容

小于几百的使用铝电解电容与钽电容, 更大的使用铝电解电容

高温的环境使用陶瓷电容或者钽电容, 低温的时候一般都可以使用

#### 耐压封装

陶瓷电容的耐压性能比较好, 一般来说封装比较大的耐压值也比较大

> 示例: 5V的电源滤波, 可以使用一个10uF/6.3V的陶瓷电容以及一个100uF/6.3V的铝电解电容, 或者一个47uF/10V的钽电容
>
> 使用两个电容的原因是去除高频和低频信号

#### 滤波特性



#### 等效串联电阻



> 在谐振的时候的频率

#### 温度特性



### 陶瓷电容

[关于MLCC陶瓷电容，这篇总结得太全面了_陶瓷电容esr对照表-CSDN博客](https://blog.csdn.net/plane1plane/article/details/123522374)



MLCC(Multi-layer Ceramic Capacitors)片式多层陶瓷电容, 是由印好电极（内电极）的陶瓷介质膜片以错位的方式叠合起来，经过一次性高温烧结形成陶瓷芯片，再在芯片的两端封上金属层（外电极），从而形成一个类似独石的结构体，故也叫独石电容器。

> 频率特性比较好, 不同的介质做成的电容器的特性不同，有容量大的，有温度特性好的，有频率特性好的等等，这也是为什么陶瓷电容有这么多种类的原因。



不同的封装可以达到的最大值不同

> 0402 - 4.7uF/6.3V
>
> 0603 - 22uF/6.3V
>
> 0805 - 47uF/6.3V

陶瓷电容常见的额定电压有：2.5V、4V、6.3V、10V、16V、25V、50V、63V、100V、200V、250V、450V、500V、630V、1KV、1.5KV、2KV、2.5KV、3KV等等。

> 实际选用的时候一般要有一个70%的余量

在实际读取大小的时候和电阻类似, 但是单位是pF, 还是使用R作为小数点

#### 类型

同介质种类由于它的主要极化类型不一样，其对电场变化的响应速度和极化率亦不一样。在相同的体积下的容量就不同，随之带来的电容器的介质损耗、容量稳定性等也就不同。介质材料划按容量的温度稳定性可以分为两类，即Ⅰ类陶瓷电容器和Ⅱ类陶瓷电容器， NPO属于Ⅰ类陶瓷，而其他的X7R、X5R、Y5V、Z5U等都属于Ⅱ类陶瓷。

MLCC陶瓷电容主要分为2大类：高节介电常数型和温度补偿型



> I类一般用于振荡器电路, 谐振电路
>
> II类一般用于旁路, 耦合以及其他要求不高的场合

### 铝电解电容

[铝电解电容_铝电解电容器主要由什么构成-CSDN博客](https://blog.csdn.net/weixin_47911361/article/details/112983754)

电容的容量比较大, 耐压比较好, 价格便宜

但是ESR比较大, 耐温比较差

> ESR比较大的话可能会导致纹波增大
>
> 耐低温能力差, 低温的时候ESR增大, 电容也下降(比较少)



阳极: 铝板的氧化膜

中间通过电解液和阴极(铝板)进行分割

> 如果加正向电压会破坏氧化铝, 阴极上面只有少量的氧化膜, 电容可以承受的电压和氧化膜的厚度有关导致反向击穿

#### 损坏正切值



电解电容等效电路如上图（忽略了绝缘电阻），当频率为 120Hz（一般电容器标称的损耗角就是在此频率下测得的）时，频率相对等效串联电感 L 非常低，因此可以忽略 L，损耗角模型如下图：



实际是有功功率和有功功率的比值

#### 漏电流

施加直流电的时候, 氧化铝允许电流通过, 这一个部分的电流是漏电流

当温度升高时，漏电流增加；温度降低，漏电流减少施加的电压降低，漏电流值也会减少。

漏电流会随时间而变化，如图所示、随时间而减小后会达到一个稳定值。因此，漏电流的规格值为 20℃下施加额定电压一段时间之后所测量的值。



### 钽电解电容







改善一些铝电解电容不好的性质, ERS比较小, 耐温比较好, 但是价格贵, 耐压不好

在实际读取的时候, 上面标注的字母是耐压的等级

| E | G | J | A | C | D | E | V | T |
| ---- | ---- | ---- | ---- | ---- | ---- | ---- | ---- | ---- |
| 2.5V | 4V | 6.3V | 10V  | 16V  | 20V  | 25V  | 35V  | 50V  |

### 安规电容器

[差模干扰，共模干扰的原理，以及解决方案_差模电感原理图-CSDN博客](https://blog.csdn.net/qq_45675261/article/details/132620767)

电容器失效以后不会电击, 危机人身的安全电容器

X电容: 跨接在零线以及火线之间的电容, 用于差模滤波

Y电容: 零线和地线之间, 火线和地线之间, 用于共模滤波









> 这一个信号同时把火线和零线加了一个电源, 这里把这一个电源导向地面



> 有一个高频的差模信号的时候, 电容的阻抗很小, 这一个信号是两个线之间的, 之间通过这一个线导出去
>
> 
>
> 

## 电感



> 空气和铜的磁导率接近, 铁的磁导率要大得多

在设计电路的时候要注意要给电感一个可靠的回路, 以及注意继电器等器件里面有线圈(续流二极管)







低频的时候和理想电感十分的相似, 一般是小于十分之一的自谐频率, 使用电感进行滤波的时候, 工作频率需要低于谐振频率



在频率非常小的时候等效为电阻

### 选型

#### 电流

+ 饱和电流 lsat

电感值衰减30%的时候的偏置电路

> 电感的值在电流增大的时候会减少, 电感的磁芯是有一定限制的, 达到饱和以后阻碍作用不再变化
>
> 在实际选型的时候瞬间值是不可以超过这一个饱和电流的

+ 温升电流 lrms

实际的电感在使用的时候会发热, 这一个电流指的是电感的自我升温不超过40℃的时候的电流

+ 额定电流 lrat

这一个是前两个电流里面的最小值, 在实际使用的时候一般需要最少有20%的余量

> 在手册里面有时候会有一个最大值和一个典型值, 一般典型值是厂家实际测试出来的值, 最大值是用户推荐使用的值, 所以最大值比典型值要小

#### 直流电阻DCR

导线一般是由导线烧制的, 是有一个直流电阻的

一般来说, 电感量比较大, 导线比较长, DCR大, 相同的电感量, 额定电流比较大, 导线比较粗, DCR小

#### 种类

依据铁芯的不同类型, 主要有环形, E型, 工字型

依据铁芯的材质来说, 主要有陶瓷芯, 铁氧体, 粉末铁芯

封装有绕线式, 多层式, 绕线又有非遮蔽式, 加磁胶之半遮蔽式以及遮蔽式

> 在其他器件不容易被影响的时候, 可以选用非隐蔽式

+ 工艺

1. 绕线电感
2. 叠层电感, 丝网印刷, 贴片式
3. 薄膜电感
4. 一体成型

### 功率电感

体积比较大, 但是可以承受比较大的功率

### 贴片电感

体积比较小, 主要用在高频电路, 电感量比较小, DCR比较大, 温升电流比较小, 自谐频率高

手册里面一般会有一个Q值, 无功功率比上有功功率

### 共模差模电感



> 差模电感可以用于单一线路上的突变
>
> 共模电感, 两条线同时产生电流突变的时候会有一个大的磁场, 抑制突变

## 磁珠

单位是欧姆, 消耗高频的能量, 电感使用的时候希望的是消耗比较小, 磁珠是利用他的损耗

它等效于电阻和电感串联，但电阻值和电感值都随频率变化。它比普通的电感有更好的高频滤波特性，在高频时呈现阻性，所以能在相当宽的频率范围内保持较高的阻抗，从而提高调频滤波效果。

主要的损耗是磁损耗以及涡流损耗, 和磁芯材料有关

使用的时候一般需要是在谐振频率附近

> 它等效于电阻和电感串联，但电阻值和电感值都随频率变化。它比普通的电感有更好的高频滤波特性，在高频时呈现阻性，所以能在相当宽的频率范围内保持较高的阻抗，从而提高调频滤波效果。

## 半导体

1. 热敏性, 温度升高的时候导电能力加强
2. 光敏性
3. 参杂性, 加入一部分杂质以后导电的能力会发生变化

本征半导体: 没有杂质以及晶格缺陷的半导体, 结构稳定

### 二极管

[【硬件基础4】二极管（原理、特性、类型、电路分析）_双稳压管2dw232数据手册-CSDN博客](https://blog.csdn.net/ARM_qiao/article/details/125868788)





+ PN结不加外部电源时：内部处于动态平衡，此时电流I=0
+ 外加正向电压：u<Uon时，正向电流几乎为0，PN结未导通；u>Uon时，正向电流 I 随电压增大而指数增加。
+ 外加反向电压：|u|<|Ubr|时，反向电流 i = Is，Is很小，通常忽略不计；|u|>|Ubr|时，反向电流 I 急剧增加，称之为反向击穿。
+ Uon为正向导通电压    Ubr为反向击穿电压 

最大整流电流 ：管子长期运行时，允许通过最大正向平均电流，电流太大会发热烧坏。
反向击穿电压：反向击穿电压值
反向电流：未击穿时，其值越小，管子的单向导电性越好，反向电流会随温度增加而增加。
极间电容：，扩散电容＋势垒电容，高频或开关状态运用时。
反向恢复时间：二极管在极性变化时不能瞬时完全变化（极间电容）。

### 稳压二极管

利用二极管的反向击穿以后电流特性, 电流变化电压基本不变的特性

### PMOS和NMOS



NMOS是栅极高电平（|VGS| > Vt）导通,低电平断开,可用来控制与地之间的导通。
PMOS是栅极低电平（|VGS| > Vt）导通,高电平断开,可用来控制与电源之间的导通。

**NMOS的特性，Vgs大于一定的值就会导通，适合用于源极接地时的情况（低端驱动）**，只要栅极电压达到4V或10V就可以了。
**PMOS的特性，Vgs小于一定的值就会导通，适合用于源极接VCC时的情况（高端驱动）**。但是，虽然PMOS可以很方便地用作高端驱动，但由于导通电阻大，价格贵，替换种类少等原因，在高端驱动中，通常还是使用NMOS。

> NMOS管实际的原理是使用栅极连接一个比较高的电压, 这时候他会吸收电子, 电子和两个N极构成一个N沟道, 可以进行导电
>
> 
>
> 图形里面的N代表的是电子的流动方向

#### 寄生二极管

很多时候电路图中MOS管旁边会带有一个二极管符号，这个不是人工加了一个二极管，而是MOS管自身的寄生二极管。对于NMOS，由于衬底（和S极相连）是P极，D极是N极，所以S到D相当于存在了一个二极管；对于PMOS，由于衬底（和S极相连）是N极，D极是P极，所以D到S相当于存在了一个二极管。在上文电流方向章节中有描述，对于NMOS，只要G大于S，MOS管就可以导通，并没有提到D，D是不是可以随便设置电压呢？

从这个寄生二极管可以看出，要想MOS管作为开关作用，D不可以随便设置。NMOS的D电压一般不能比S电压低，因为会导致这个寄生二极管导通，G极不管怎么样，MOS管都看起来像是直接导通了，失去了MOS开关功能。PMOS则是D电压一般不能比S电压高。

> 而实际应用电路，NMOS会有电流从S到D的情况，比如下面这个NMOS管防电源反接电路（仅仅是个示意图，实际电路需要多考虑一些因素）。
>
> 
>
> 电源正极VCC经过后级负载电路接到体二极管，那么体二极管就会导通，于是此时S极的电压就约为0.7V左右（体二极管导通电压）。
>
> 同时栅极G极接的是VCC，所以Vgs=Vcc-0.7V>Vgsth，NMOS管会导通。NMOS管导通之后，导通压降基本为0，那么Vgs=Vcc，MOS管维持导通状态。
>
> 这样整体电源通路就是通的，电源给后级负载供上了电，后级电路正常工作。
>
> 这里有一点需要特别注意，就是此时MOS管的电流是S到D的，与往常我们经常见的D到S是反的。
> 
>

#### 参数

Vgsth临界电压值, 使用的时候断开和连接的变化的时候的电压

Rdson: 实际导通的时候电阻值

Cgs: G和S之间的寄生电容, 实际使用的时候由于这一个电容的充电需要时间, 所以不是立即进行导通的, 一般这一个参数和Rdson的值是反比的关系

## 晶振

石英晶体有一种特性，如果在晶片某轴向上施加压力时，相应施力的方向会产生一定的电位, 相反的，在晶体的某些轴向施加电场时，会使晶体产生机械变形；

如果在石英晶片上加上交变电压，晶体就会产生机械振动，机械形变振动又会产生交变电场，尽管这种交变电场的电压极其微弱，但其振动频率是十分稳定的。当外加交变电压的频率与晶片的固有频率（与切割后的晶片尺寸有关，晶体愈薄，切割难度越大，谐振频率越高）相等时，机械振动的幅度将急剧增加，这种现象称为“压电谐振”。





串联谐振的时候这一个电路的阻抗最小, 之后并联谐振的时候理论这一个电路的阻抗无限大



CL=(C1*C2)/(C1+C2)+Cs



> 负载电容是晶振两个段子之间的有效电容, 实际作用是反向位
>
> [晶振旁边的两个电容起什么作用？_哔哩哔哩_bilibili](https://www.bilibili.com/video/BV17C4y117PW/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)
>
> 这一个电容如果比较大会导致起振时间变长, 有可能导致单片机的启动出现问题

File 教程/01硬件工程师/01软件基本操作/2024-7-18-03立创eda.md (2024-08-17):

---
layout: post
title: "立创EDA" 
date:   2024-7-14 15:39:08 +0800
tags: Linux 网络
---

# 立创EDA







> 在半离线模式的时候可以用这一个打开在线系统库





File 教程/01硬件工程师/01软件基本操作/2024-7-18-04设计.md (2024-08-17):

---
layout: post
title: "设计流程" 
date:   2024-7-14 15:39:08 +0800
tags: Linux 网络
---

# 设计

## 设计流程



 1、如果没有需要的库，则先画库：器件，符号，封装。器件需要绑定符号和封装。

2、新建工程，放置器件在原理图

3、原理图转PCB

4、导出BOM和Gerber下单。

> 修改注意: 添加泪滴, 测试点

## 快捷键



放大缩小: 滚轮

移动屏幕: 右键

### 元件快捷键

旋转: 空格

选择线宽: Tab

切换长度单位: q

### PCB快捷键

单路布线: w

隐藏飞线: Ctrl+r

突出走线 Shift + S

放置过孔 v

顶层T, 底层D, 用于自动打孔

高亮网络 H

重新铺铜 Shift+ B

## 新的工程









> 可以在这设置默认初始化图纸右下角的信息, 也可以直接在右边的属性表里面更改

### 图纸

在放置电压, 地和引脚的时候, 如果名字是一样的, 就会进行连接, 名字是不同的不会进行连接

连接器件的时候使用导线

实际绘制的时候需要首先从立创商城里面查找自己需要的那一个器件



### 检测DRC





> 可以在这里设置检查的规则

### 元件

最重要的引脚的放置, 线条没有物理意义, 引脚的编号是和封装绑定的



> 这些器件实际是不需要进行绘制的





名字一样的端口实际是连接在一起的



也可以使用这一种方法进行查找



#### 电阻











> 这个位号里面的?会被替换为1, 2, 3, 电阻可以使用R?
>
> 如果有封装, 图片或者3D模型可以进行绑定

使用这一个进行绘画, 这时候发现网格比较大, 所以使用





调小一点



添加引脚





> 电阻没有引脚名称可以去掉





#### LED



#### AMS1117-3.3

[【电源】【PCB】电源板(提供±2v5,3v3,5v,12v供电)的制作——电赛使用_pcb板上加多少电压-CSDN博客](https://blog.csdn.net/GalaxyerKw/article/details/125686221)

[Microsoft Word - DS1117 (szlcsc.com)](https://atta.szlcsc.com/upload/public/pdf/source/20180727/C6186_7A095716F0823C02F1997A905E26C086.pdf)

AMS1117-3.3是一种输出电压为3.3V的正向低压降稳压器，适用于高效率线性稳压器发表开关电源稳压器电池充电器活跃的小型计算机系统接口终端笔记本电脑的电源管理电池供电的仪器。

AMS1117有两个版本：固定输出版本和可调版本，固定输出电压为1.5V、1.8V、2.5V、2.85V、3.0V、3.3V、5.0V，具有1％的精度；固定输出电压为１．２Ｖ的精度为２％。

AMS1117内部集成过热保护和限流电路，是电池供电和便携式计算机的最佳选择。

特性

固定输出电压为1.5V、1.8V、2.5V、2.85V、3.0V、3.3V、5.0V和可调版本，具有1％的精度

固定输出电压为1.2V的精度为2％

低漏失电压：1A输出电流时仅为1.2V

限流功能

过热切断

温度范围：-40°C~125°C





> 1、D1作用是防止电源反接。
>
> 2、C01、C02是电源输入滤波。
>
> 3、VDD3.3是3.3V电源，供数字电路使用，
>
> 4、L1、L2是隔离滤波电感。
>
> 5、VCC3.3是3.3V电源，供模拟电路使用。







> 第四个脚是散热pad，一般和封装的中间脚是通的（也有不通的，具体参见厂家的datasheet）手册里只有三个脚是因为2、4两个脚在电气功能上是一样的，没必要单独拿出来说而已
>
> 第四脚对应的是封装的第四个焊盘，所以命名为TAB

#### microusb





### 封装

[PCB封装尺寸-0402-0603-0805-CSDN博客](https://blog.csdn.net/li707414287/article/details/99239656)



#### C0603

首先需要获取封装的尺寸











> 这一个焊盘的1对应元件引脚的编号



> 设置焊盘的形状以及大小



> 计算位置, 红色的是铜, 实际焊接的位置



> 电阻使用的圆角, 电感使用的是方角





> 绘制丝印





> 紫色的部分是阻焊层, 可以在焊盘属性里面进行设置, 这一层的作用是阻止覆盖绿油的
>
> 



> 选择器件以及封装进行更新
>
> 

#### C0402



#### C0805



#### F1201





#### 排针





> 可以使用这一个快速放置





#### USB





内直径是实际这一个孔的直径, 外直径是外面有一个铜皮的直径

固定脚使用的是多层的焊盘



### PCB

原理图转PCB







> 这一个蓝色的线是飞线层

**网络:** 相同网络的铜是需要连接在一起的





> 导出的数据实际是器件的json数据

#### 板框









#### 布局

在原理图部分选中的时候, PCB也会进行选中, 之后就可以把器件按照模块拖动出来



丝印一般会把他放在器件的中间位置





可以选择所有的丝印





在布局的时候可以使用Ctrl+r隐藏飞线, 这个时候飞线只有在移动期间的时候才会显示





> 按照大概得走线进行布局

#### 设计规则







[PCB走线载流计算器-电子技术资料工具-电子发烧友 (elecfans.com)](https://www.elecfans.com/tools/108.html)













+ 差分信号









> 
>
> 全填充的连接方式, 机器焊接的时候一般使用这一个
>
> 
>
> 使用发散的模式, 手工焊接的时候一般使用这一个

#### 布线

快捷键w



可以使用shift+s突出走线

正面连线的时候不需要考虑GND, 反面会大面积铺地



##### 底层布线



这一个eda在切换层的时候会自动打孔, 设置一下切换的快捷键, 顶层T, 底层D

##### 特殊

+ 晶振的外部需要包地处理



之后需要进行打孔, 快捷键V



在最后铺GND的时候这一个还需要禁止铺铜的操作

##### 电源线

可以使用铺铜的方式





改变规则以后可以使用这一个重新加载





> 填充和铺铜的区别的不会自动避让

##### 差分线

使用差分线布线



##### GND



只有这一个没有处理了

首先需要隔离晶振





之后直接选中底层进行铺铜









可以加强PCB的韧性

##### 增加泪滴







##### 丝印图片



#### 底层设计

在底层设计的时候, 需要把这一个板子进行翻转



### 3D模型



## 下单



[嘉立创客户中心 (jlc.com)](https://member.jlc.com/integrated/content/couponList)

领取以后可以进行下单





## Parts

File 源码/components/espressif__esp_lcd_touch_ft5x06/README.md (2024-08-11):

# ESP LCD Touch FT5x06 Controller



Implementation of the FT5x06 touch controller with esp_lcd_touch component.

| Touch controller | Communication interface | Component name | Link to datasheet |
| :---: | :---: | :---: | :---: |
| FT5x06 | I2C (SPI [^1]) | esp_lcd_touch_ft5x06 | [PDF](https://www.displayfuture.com/Display/datasheet/controller/FT5x06.pdf) |

[^1]: **NOTE:** This controller should work via I2C or SPI communication interface. But it was tested on HW only via I2C communication interface.

## Add to project

Packages from this repository are uploaded to [Espressif's component service](https://components.espressif.com/).
You can add them to your project via `idf.py add-dependancy`, e.g.
```
    idf.py add-dependency esp_lcd_touch_ft5x06==1.0.0
```

Alternatively, you can create `idf_component.yml`. More is in [Espressif's documentation](https://docs.espressif.com/projects/esp-idf/en/latest/esp32/api-guides/tools/idf-component-manager.html).

## Example use

I2C initialization of the touch component.

```
    esp_lcd_panel_io_i2c_config_t io_config = ESP_LCD_TOUCH_IO_I2C_FT5x06_CONFIG();

    esp_lcd_touch_config_t tp_cfg = {
        .x_max = CONFIG_LCD_HRES,
        .y_max = CONFIG_LCD_VRES,
        .rst_gpio_num = -1,
        .int_gpio_num = -1,
        .levels = {
            .reset = 0,
            .interrupt = 0,
        },
        .flags = {
            .swap_xy = 0,
            .mirror_x = 0,
            .mirror_y = 0,
        },
    };

    esp_lcd_touch_handle_t tp;
    esp_lcd_touch_new_i2c_ft5x06(io_handle, &tp_cfg, &tp);
```

Read data from the touch controller and store it in RAM memory. It should be called regularly in poll.

```
    esp_lcd_touch_read_data(tp);
```

Get one X and Y coordinates with strength of touch.

```
    uint16_t touch_x[1];
    uint16_t touch_y[1];
    uint16_t touch_strength[1];
    uint8_t touch_cnt = 0;

    bool touchpad_pressed = esp_lcd_touch_get_coordinates(tp, touch_x, touch_y, touch_strength, &touch_cnt, 1);
```

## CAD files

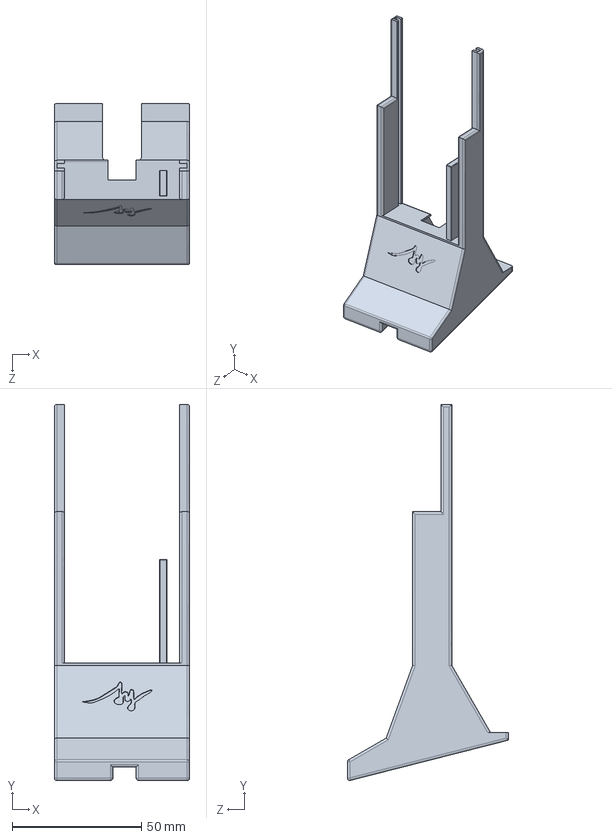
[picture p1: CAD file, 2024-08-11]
3D外壳/外壳.SLDPRT
52.4 x 145.6 x 62.4 mm

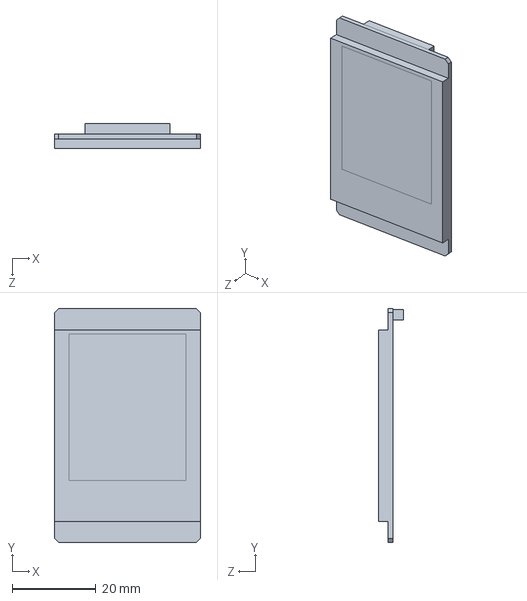
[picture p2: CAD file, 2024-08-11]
3D外壳/SPI1.8寸屏幕.SLDPRT
35.0 x 56.0 x 5.99 mm

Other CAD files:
3D外壳/外壳.3mf

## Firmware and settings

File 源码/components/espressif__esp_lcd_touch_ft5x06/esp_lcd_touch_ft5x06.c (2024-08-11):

/*
 * SPDX-FileCopyrightText: 2015-2023 Espressif Systems (Shanghai) CO LTD
 *
 * SPDX-License-Identifier: Apache-2.0
 */

#include <stdio.h>
#include <string.h>
#include "freertos/FreeRTOS.h"
#include "freertos/task.h"
#include "esp_system.h"
#include "esp_err.h"
#include "esp_log.h"
#include "esp_check.h"
#include "driver/gpio.h"
#include "driver/i2c.h"
#include "esp_lcd_panel_io.h"
#include "esp_lcd_touch.h"

static const char *TAG = "FT5x06";

/* Registers */
#define FT5x06_DEVICE_MODE      (0x00)
#define FT5x06_GESTURE_ID       (0x01)
#define FT5x06_TOUCH_POINTS     (0x02)

#define FT5x06_TOUCH1_EV_FLAG   (0x03)
#define FT5x06_TOUCH1_XH        (0x03)
#define FT5x06_TOUCH1_XL        (0x04)
#define FT5x06_TOUCH1_YH        (0x05)
#define FT5x06_TOUCH1_YL        (0x06)

#define FT5x06_TOUCH2_EV_FLAG   (0x09)
#define FT5x06_TOUCH2_XH        (0x09)
#define FT5x06_TOUCH2_XL        (0x0A)
#define FT5x06_TOUCH2_YH        (0x0B)
#define FT5x06_TOUCH2_YL        (0x0C)

#define FT5x06_TOUCH3_EV_FLAG   (0x0F)
#define FT5x06_TOUCH3_XH        (0x0F)
#define FT5x06_TOUCH3_XL        (0x10)
#define FT5x06_TOUCH3_YH        (0x11)
#define FT5x06_TOUCH3_YL        (0x12)

#define FT5x06_TOUCH4_EV_FLAG   (0x15)
#define FT5x06_TOUCH4_XH        (0x15)
#define FT5x06_TOUCH4_XL        (0x16)
#define FT5x06_TOUCH4_YH        (0x17)
#define FT5x06_TOUCH4_YL        (0x18)

#define FT5x06_TOUCH5_EV_FLAG   (0x1B)
#define FT5x06_TOUCH5_XH        (0x1B)
#define FT5x06_TOUCH5_XL        (0x1C)
#define FT5x06_TOUCH5_YH        (0x1D)
#define FT5x06_TOUCH5_YL        (0x1E)

#define FT5x06_ID_G_THGROUP             (0x80)
#define FT5x06_ID_G_THPEAK              (0x81)
#define FT5x06_ID_G_THCAL               (0x82)
#define FT5x06_ID_G_THWATER             (0x83)
#define FT5x06_ID_G_THTEMP              (0x84)
#define FT5x06_ID_G_THDIFF              (0x85)
#define FT5x06_ID_G_CTRL                (0x86)
#define FT5x06_ID_G_TIME_ENTER_MONITOR  (0x87)
#define FT5x06_ID_G_PERIODACTIVE        (0x88)
#define FT5x06_ID_G_PERIODMONITOR       (0x89)
#define FT5x06_ID_G_AUTO_CLB_MODE       (0xA0)
#define FT5x06_ID_G_LIB_VERSION_H       (0xA1)
#define FT5x06_ID_G_LIB_VERSION_L       (0xA2)
#define FT5x06_ID_G_CIPHER              (0xA3)
#define FT5x06_ID_G_MODE                (0xA4)
#define FT5x06_ID_G_PMODE               (0xA5)
#define FT5x06_ID_G_FIRMID              (0xA6)
#define FT5x06_ID_G_STATE               (0xA7)
#define FT5x06_ID_G_FT5201ID            (0xA8)
#define FT5x06_ID_G_ERR                 (0xA9)

/*******************************************************************************
* Function definitions
*******************************************************************************/
static esp_err_t esp_lcd_touch_ft5x06_read_data(esp_lcd_touch_handle_t tp);
static bool esp_lcd_touch_ft5x06_get_xy(esp_lcd_touch_handle_t tp, uint16_t *x, uint16_t *y, uint16_t *strength, uint8_t *point_num, uint8_t max_point_num);
static esp_err_t esp_lcd_touch_ft5x06_del(esp_lcd_touch_handle_t tp);

/* I2C read */
static esp_err_t touch_ft5x06_i2c_write(esp_lcd_touch_handle_t tp, uint8_t reg, uint8_t data);
static esp_err_t touch_ft5x06_i2c_read(esp_lcd_touch_handle_t tp, uint8_t reg, uint8_t *data, uint8_t len);

/* FT5x06 init */
static esp_err_t touch_ft5x06_init(esp_lcd_touch_handle_t tp);
/* FT5x06 reset */
static esp_err_t touch_ft5x06_reset(esp_lcd_touch_handle_t tp);

/*******************************************************************************
* Public API functions
*******************************************************************************/

esp_err_t esp_lcd_touch_new_i2c_ft5x06(const esp_lcd_panel_io_handle_t io, const esp_lcd_touch_config_t *config, esp_lcd_touch_handle_t *out_touch)
{
    esp_err_t ret = ESP_OK;

    assert(config != NULL);
    assert(out_touch != NULL);

    /* Prepare main structure */
    esp_lcd_touch_handle_t esp_lcd_touch_ft5x06 = heap_caps_calloc(1, sizeof(esp_lcd_touch_t), MALLOC_CAP_DEFAULT);
    ESP_GOTO_ON_FALSE(esp_lcd_touch_ft5x06, ESP_ERR_NO_MEM, err, TAG, "no mem for FT5x06 controller");

    /* Communication interface */
    esp_lcd_touch_ft5x06->io = io;

    /* Only supported callbacks are set */
    esp_lcd_touch_ft5x06->read_data = esp_lcd_touch_ft5x06_read_data;
    esp_lcd_touch_ft5x06->get_xy = esp_lcd_touch_ft5x06_get_xy;
    esp_lcd_touch_ft5x06->del = esp_lcd_touch_ft5x06_del;

    /* Mutex */
    esp_lcd_touch_ft5x06->data.lock.owner = portMUX_FREE_VAL;

    /* Save config */
    memcpy(&esp_lcd_touch_ft5x06->config, config, sizeof(esp_lcd_touch_config_t));

    /* Prepare pin for touch interrupt */
    if (esp_lcd_touch_ft5x06->config.int_gpio_num != GPIO_NUM_NC) {
        const gpio_config_t int_gpio_config = {
            .mode = GPIO_MODE_INPUT,
            .intr_type = (esp_lcd_touch_ft5x06->config.levels.interrupt ? GPIO_INTR_POSEDGE : GPIO_INTR_NEGEDGE),
            .pin_bit_mask = BIT64(esp_lcd_touch_ft5x06->config.int_gpio_num)
        };
        ret = gpio_config(&int_gpio_config);
        ESP_GOTO_ON_ERROR(ret, err, TAG, "GPIO config failed");

        /* Register interrupt callback */
        if (esp_lcd_touch_ft5x06->config.interrupt_callback) {
            esp_lcd_touch_register_interrupt_callback(esp_lcd_touch_ft5x06, esp_lcd_touch_ft5x06->config.interrupt_callback);
        }
    }

    /* Prepare pin for touch controller reset */
    if (esp_lcd_touch_ft5x06->config.rst_gpio_num != GPIO_NUM_NC) {
        const gpio_config_t rst_gpio_config = {
            .mode = GPIO_MODE_OUTPUT,
            .pin_bit_mask = BIT64(esp_lcd_touch_ft5x06->config.rst_gpio_num)
        };
        ret = gpio_config(&rst_gpio_config);
        ESP_GOTO_ON_ERROR(ret, err, TAG, "GPIO config failed");
    }

    /* Reset controller */
    ret = touch_ft5x06_reset(esp_lcd_touch_ft5x06);
    ESP_GOTO_ON_ERROR(ret, err, TAG, "FT5x06 reset failed");

    /* Init controller */
    ret = touch_ft5x06_init(esp_lcd_touch_ft5x06);
    ESP_GOTO_ON_ERROR(ret, err, TAG, "FT5x06 init failed");

err:
    if (ret != ESP_OK) {
        ESP_LOGE(TAG, "Error (0x%x)! Touch controller FT5x06 initialization failed!", ret);
        if (esp_lcd_touch_ft5x06) {
            esp_lcd_touch_ft5x06_del(esp_lcd_touch_ft5x06);
        }
    }

    *out_touch = esp_lcd_touch_ft5x06;

    return ret;
}
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

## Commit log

2024-08-17 2024-8-17-添加一部分教程
2024-09-07 2024-9-7-补充教程手册
